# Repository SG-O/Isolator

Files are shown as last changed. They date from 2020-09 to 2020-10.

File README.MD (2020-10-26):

# Triple Isolator for two Step/Dir/En and one UART signal #

This was designed to be used with the [ODrive](https://github.com/madcowswe/ODrive "ODrive") motor controller. It may be useful for other things though.

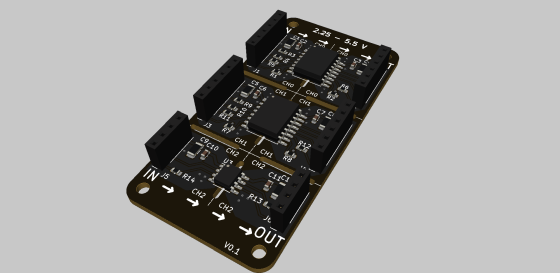
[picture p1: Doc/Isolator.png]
Isolator Image


## Documentation ##

You can find the manufacturing documentation [here.](https://github.com/SG-O/Isolator/tree/master/Doc)

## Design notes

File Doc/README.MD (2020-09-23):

# Manufacturing Documentation #

## Schematic ##

You can view the schematic [here.](https://github.com/SG-O/Isolator/blob/master/Doc/Isolator.pdf "Schematic")

## Gerber Files ##

Gerber files for a single board or a panelized version can be found [here.](https://github.com/SG-O/Isolator/releases "Releases")

## BOM ##

The BOM is available [here.](https://github.com/SG-O/Isolator/blob/master/Doc/Isolator.csv "BOM")

## Dimension ##

Mounting hole positions and board dimension can be found [here.](https://github.com/SG-O/Isolator/blob/master/Doc/Isolator-brd.svg "Dimensions")

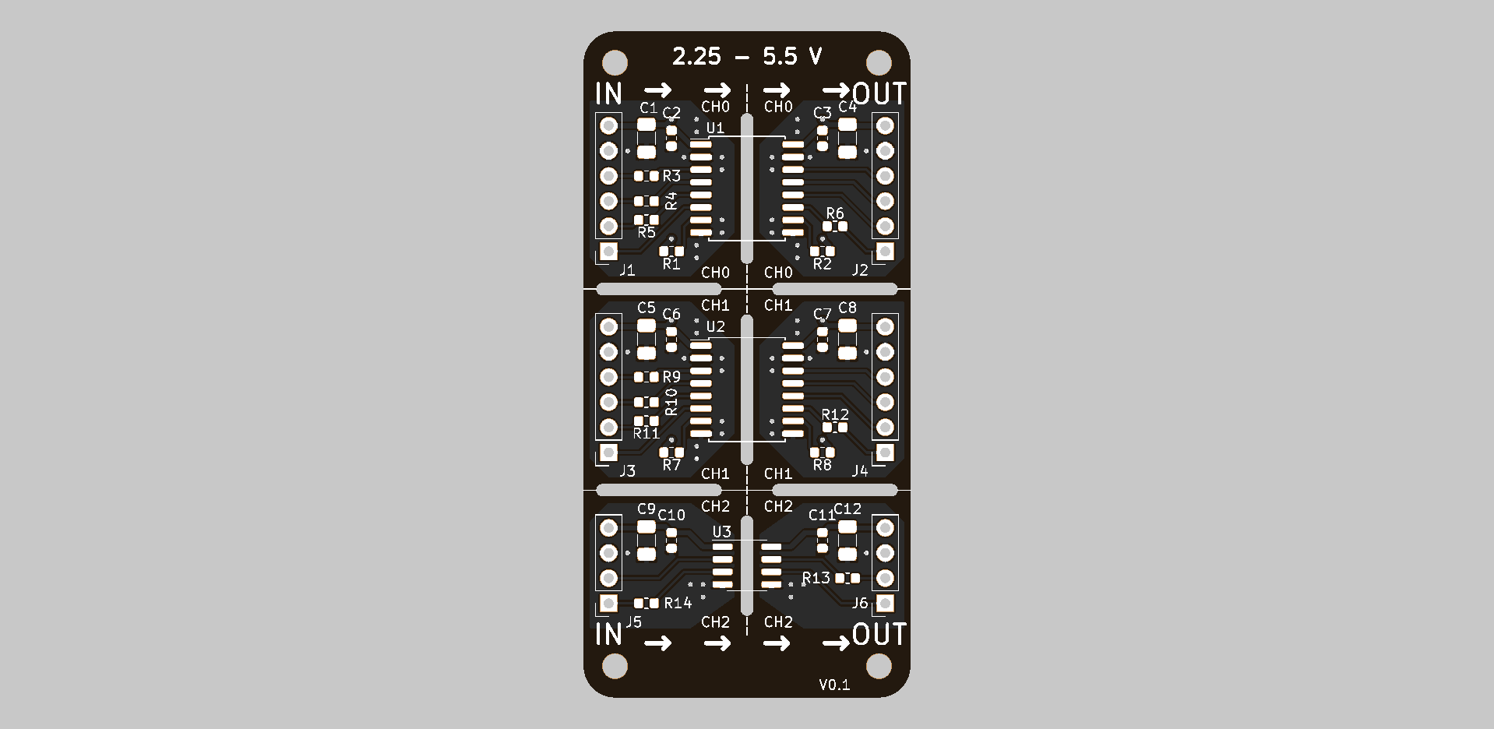
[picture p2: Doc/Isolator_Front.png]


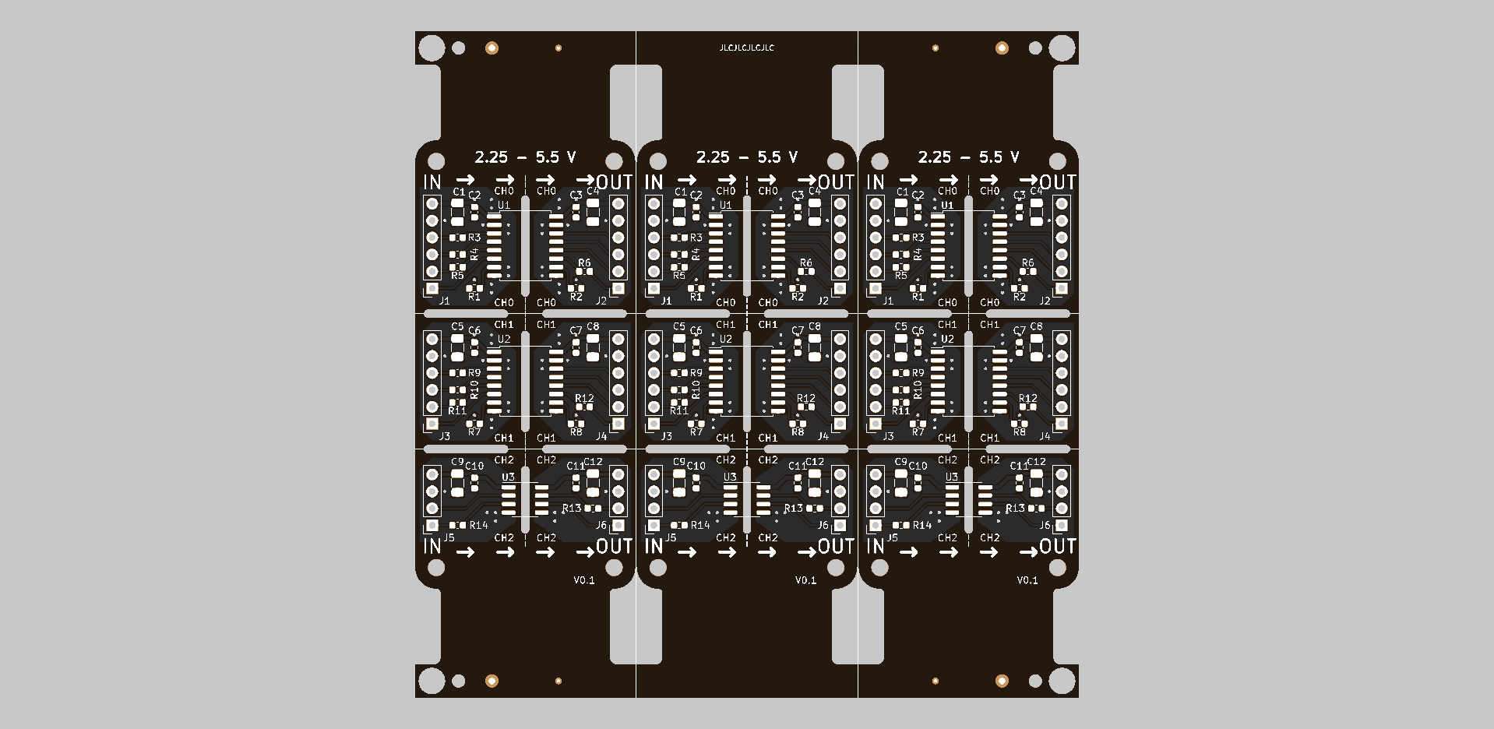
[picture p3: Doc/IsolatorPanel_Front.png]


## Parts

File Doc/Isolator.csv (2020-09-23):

Component | Description | Part | References | Value | Footprint | Quantity Per PCB | Datasheet | manf# | lcsc#
1 | Unpolarized capacitor | C | C2 C3 C6 C7 C10 C11 | 100n | C_0603_1608Metric | 6 |  | CL10B104KB8NNNC | C1591
2 | Unpolarized capacitor | C | C1 C4 C5 C8 C9 C12 | 10u | R_1206_3216Metric | 6 |  | CL31B106KBHNNNE | C89632
3 | Generic connector, single row, 01x06, script generated (kicad-library-utils/schlib/autogen/connector/) | Conn_01x06_Female | J1 | Step_0_In | PinSocket_1x06_P2.54mm_Vertical | 1
4 | Generic connector, single row, 01x06, script generated (kicad-library-utils/schlib/autogen/connector/) | Conn_01x06_Female | J2 | Step_0_Out | PinSocket_1x06_P2.54mm_Vertical | 1
5 | Generic connector, single row, 01x06, script generated (kicad-library-utils/schlib/autogen/connector/) | Conn_01x06_Female | J3 | Step_1_In | PinSocket_1x06_P2.54mm_Vertical | 1
6 | Generic connector, single row, 01x06, script generated (kicad-library-utils/schlib/autogen/connector/) | Conn_01x06_Female | J4 | Step_1_Out | PinSocket_1x06_P2.54mm_Vertical | 1
7 | Generic connector, single row, 01x04, script generated (kicad-library-utils/schlib/autogen/connector/) | Conn_01x04_Female | J5 | UART_In | PinSocket_1x04_P2.54mm_Vertical | 1
8 | Generic connector, single row, 01x04, script generated (kicad-library-utils/schlib/autogen/connector/) | Conn_01x04_Female | J6 | UART_Out | PinSocket_1x04_P2.54mm_Vertical | 1
9 | Resistor | R | R3 R4 R5 R6 R9 R10 R11 R12 R13 R14 | 0R | R_0603_1608Metric | 10 |  | 0603WAF0000T5E | C21189
10 | Resistor | R | R1 R2 R7 R8 | 4.7k | R_0603_1608Metric | 4 |  | 0603WAF4701T5E | C23162
11 | Low Power Dual-Channel 1/1 Digital Isolator, 25Mbps 33ns, Fail-Safe High, SO8 | ISO7321C | U3 | ISO6721 / ISO7721 | SOIC-8_3.9x4.9mm_P1.27mm | 1 | http://www.ti.com/general/docs/lit/getliterature.tsp?genericPartNumber=iso7321c&fileType=pdf | ISO7721FDR
12 | Low Power Quad-Channel 3/1 Digital Isolator, 25Mbps 31ns, Fail-Safe High, SO16 | ISO7341FC | U1 U2 | ISO6741 / ISO7741 | SOIC-16W_7.5x10.3mm_P1.27mm | 2 | http://www.ti.com/general/docs/lit/getliterature.tsp?genericPartNumber=iso7341c&fileType=pdf | ISO7741FDWR
Component Groups: | 12
Component Count: | 35
Fitted Components: | 35
Number of PCBs: | 1
Total components: | 35
Schematic Version: | 0.1
Schematic Date: | 2020-09-23
BoM Date: | 23.09.2020 17:55:18
Schematic Source: | C:\Users\User\Documents\Git\Isolator\Isolator.sch
KiCad Version: | Eeschema (5.1.5)-3

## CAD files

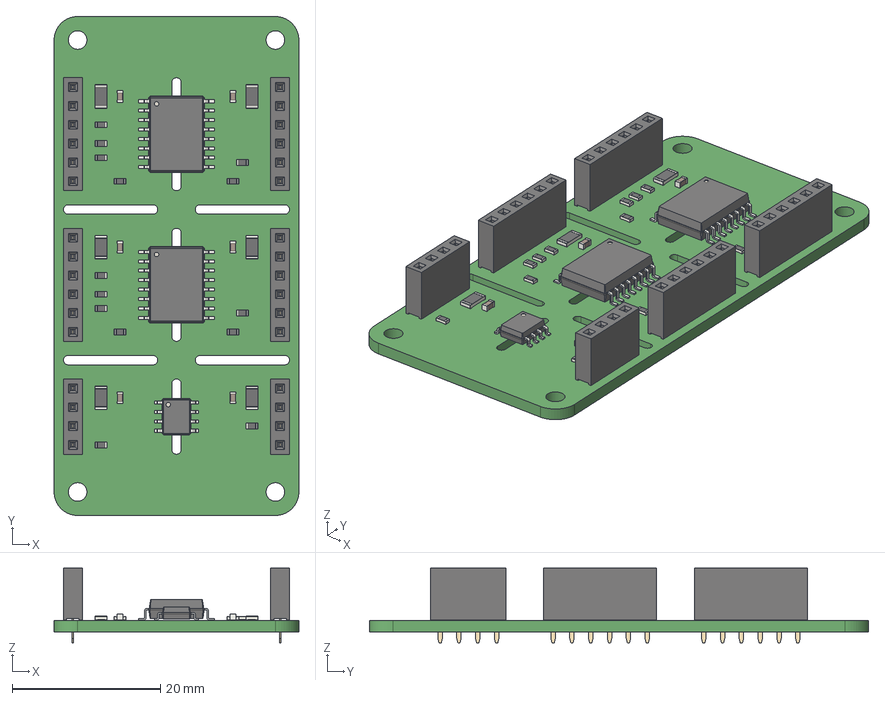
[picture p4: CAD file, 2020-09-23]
3D/Isolator.step
33.0 x 67.3 x 10.1 mm

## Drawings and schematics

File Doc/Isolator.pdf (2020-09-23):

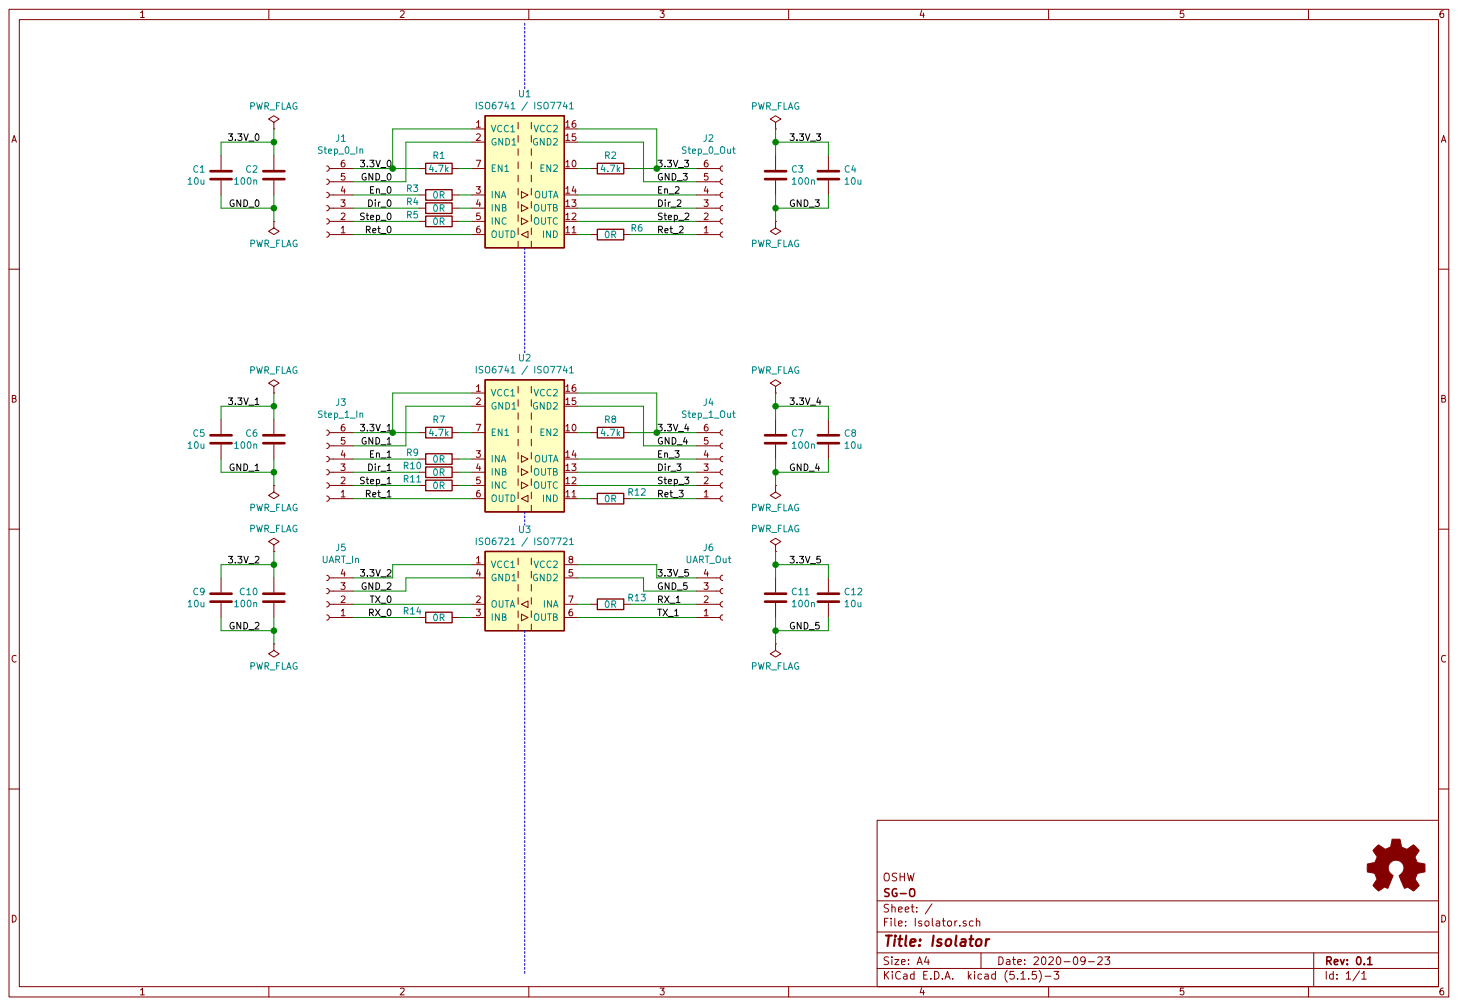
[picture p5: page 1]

OSHW
Id: 1/1 Title: Isolator File: Isolator.sch Sheet: / SG-O

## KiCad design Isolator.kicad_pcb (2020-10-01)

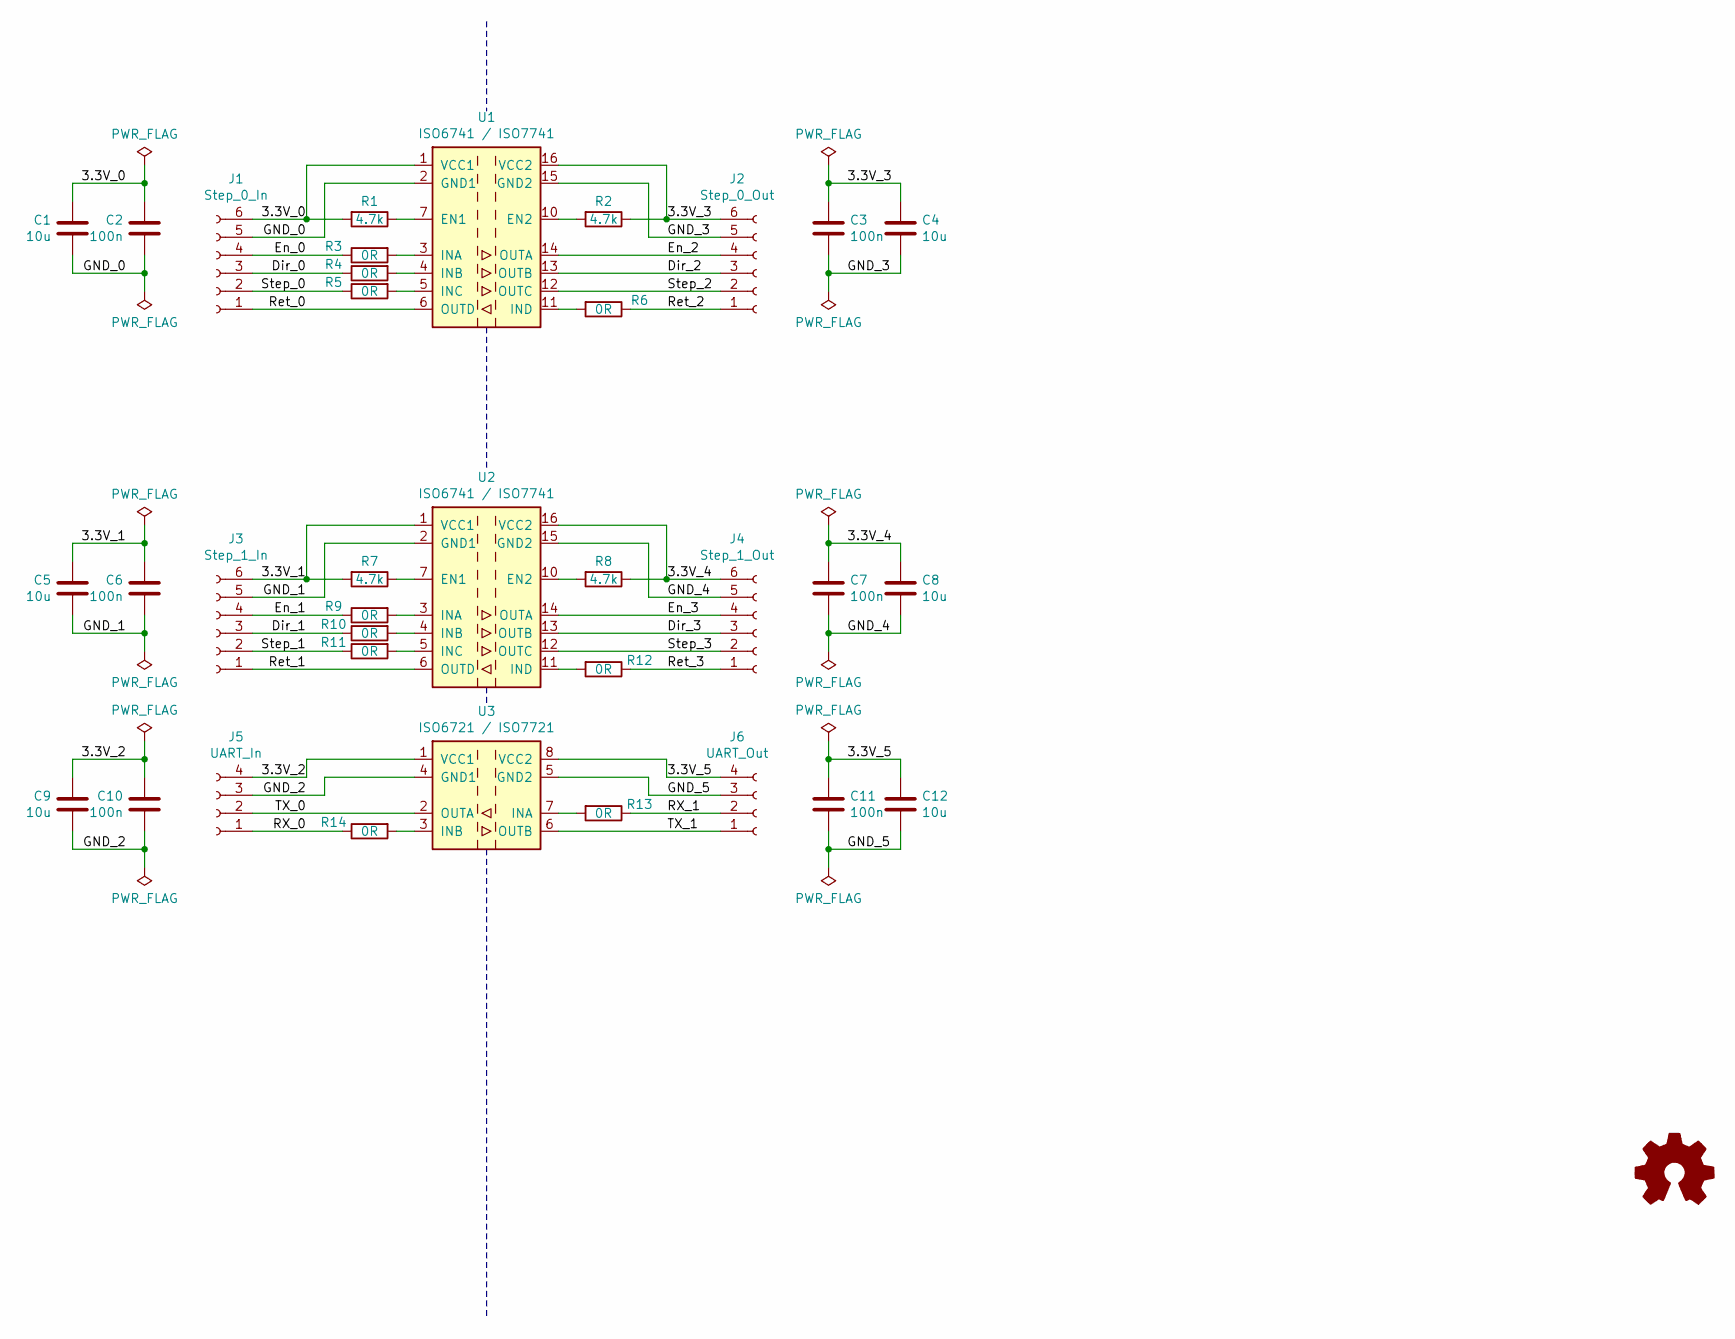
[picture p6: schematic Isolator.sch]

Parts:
C1, C4, C5, C8, C9, C12: 10u; R_1206_3216Metric; lcsc# C89632
C2, C3, C6, C7, C10, C11: 100n; C_0603_1608Metric; lcsc# C1591
J1: Step_0_In; PinSocket_1x06_P2.54mm_Vertical
J2: Step_0_Out; PinSocket_1x06_P2.54mm_Vertical
J3: Step_1_In; PinSocket_1x06_P2.54mm_Vertical
J4: Step_1_Out; PinSocket_1x06_P2.54mm_Vertical
J5: UART_In; PinSocket_1x04_P2.54mm_Vertical
J6: UART_Out; PinSocket_1x04_P2.54mm_Vertical
R1, R2, R7, R8: 4.7k; R_0603_1608Metric; lcsc# C23162
R3, R4, R5, R6, R9, R10, R11, R12, R13, R14: 0R; R_0603_1608Metric; lcsc# C21189
U1, U2: ISO6741 / ISO7741; SOIC-16W_7.5x10.3mm_P1.27mm
U3: ISO6721 / ISO7721; SOIC-8_3.9x4.9mm_P1.27mm

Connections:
/3.3V_0: C1.1, C2.1, J1.6, R1.2, U1.1 (VCC1)
/3.3V_1: C5.1, C6.1, J3.6, R7.2, U2.1 (VCC1)
/3.3V_2: C9.1, C10.1, J5.4, U3.1 (VCC1)
/3.3V_3: C3.1, C4.1, J2.6, R2.1, U1.16 (VCC2)
/3.3V_4: C7.1, C8.1, J4.6, R8.1, U2.16 (VCC2)
/3.3V_5: C11.1, C12.1, J6.4, U3.8 (VCC2)
/Dir_0: J1.3, R4.1
/Dir_1: J3.3, R10.1
/Dir_2: J2.3, U1.13 (OUTB)
/Dir_3: J4.3, U2.13 (OUTB)
/En_0: J1.4, R3.1
/En_1: J3.4, R9.1
/En_2: J2.4, U1.14 (OUTA)
/En_3: J4.4, U2.14 (OUTA)
/GND_0: C1.2, C2.2, J1.5, U1.2 (GND1), U1.8 (GND1)
/GND_1: C5.2, C6.2, J3.5, U2.2 (GND1), U2.8 (GND1)
/GND_2: C9.2, C10.2, J5.3, U3.4 (GND1)
/GND_3: C3.2, C4.2, J2.5, U1.9 (GND2), U1.15 (GND2)
/GND_4: C7.2, C8.2, J4.5, U2.9 (GND2), U2.15 (GND2)
/GND_5: C11.2, C12.2, J6.3, U3.5 (GND2)
/RX_0: J5.1, R14.1
/RX_1: J6.2, R13.1
/Ret_0: J1.1, U1.6 (OUTD)
/Ret_1: J3.1, U2.6 (OUTD)
/Ret_2: J2.1, R6.1
/Ret_3: J4.1, R12.1
/Step_0: J1.2, R5.1
/Step_1: J3.2, R11.1
/Step_2: J2.2, U1.12 (OUTC)
/Step_3: J4.2, U2.12 (OUTC)
/TX_0: J5.2, U3.2 (OUTA)
/TX_1: J6.1, U3.6 (OUTB)
unnamed: R1.1, U1.7 (EN1)
unnamed: R2.2, U1.10 (EN2)
unnamed: R3.2, U1.3 (INA)
unnamed: R4.2, U1.4 (INB)
unnamed: R5.2, U1.5 (INC)
unnamed: R6.2, U1.11 (IND)
unnamed: R7.1, U2.7 (EN1)
unnamed: R8.2, U2.10 (EN2)
unnamed: R9.2, U2.3 (INA)
unnamed: R10.2, U2.4 (INB)
unnamed: R11.2, U2.5 (INC)
unnamed: R12.2, U2.11 (IND)
unnamed: R13.2, U3.7 (INA)
unnamed: R14.2, U3.3 (INB)

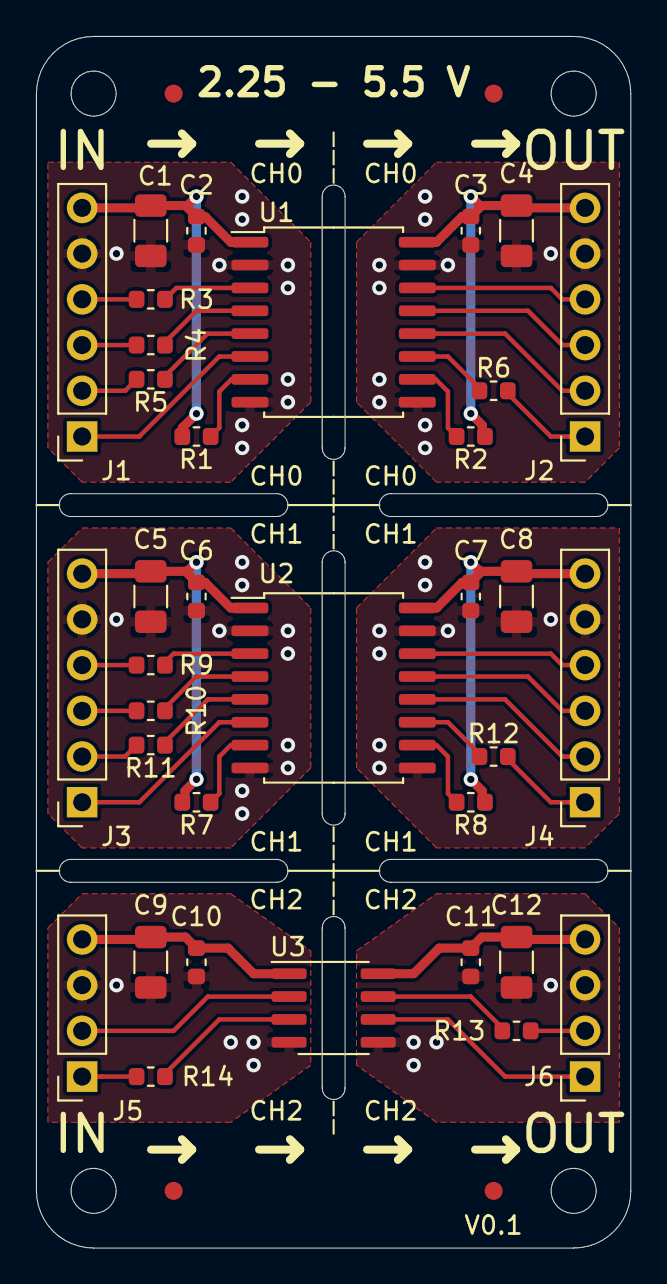
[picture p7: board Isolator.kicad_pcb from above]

Board: 2 copper layers, 33.0 x 67.3 mm, 43 parts (0 on the bottom side), 46 nets.

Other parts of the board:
 : Fiducial_1mm_Dia_2mm_Outer
 #2,  #3,  #4: Fiducial_1mm_Dia_2mm_Outer
 #5,  #6,  #7,  #8: MountingHole_2.5mm

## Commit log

2020-09-23 Added mounting holes. (They got lost somehow)
    [Isolator.kicad_pcb, Isolator.step]
2020-09-23 Added panelized version
    [IsolatorPanel.kicad_pcb]
2020-09-23 Added fiducials to single board
    [Isolator.kicad_pcb]
2020-09-23 Added BOM
    [Isolator.csv]
2020-09-23 Added board images for the panel
2020-09-23 Added dimensional drawing
    [Isolator.kicad_pcb]
2020-10-01 Switched RX and TX silkscreen
    [Isolator.kicad_pcb, IsolatorPanel.kicad_pcb]
